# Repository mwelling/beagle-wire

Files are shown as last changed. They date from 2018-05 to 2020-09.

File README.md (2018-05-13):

# beagle-wire

This repository contains the hardware design files for the BeagleWire.

The BeagleWire is an FPGA development platform that has been designed for use with BeagleBone boards.
BeagleWire is a cape on which there is FPGA device - Lattice iCE40HX. The Lattice iCE40 is a family of
FPGAs with a minimalistic architecture and very regular structure, designed for low-cost, high-volume
consumer and system applications. The significance of FPGAs is continuously increasing, as they are more
and more often used for supporting work of ARM processors. BeagleWire does not require external tools
(JTAG) and the whole software stack is Open Source. iCE40 is an energy saving device, allowing to work
with  small batteries. FPGA cape allows easy and low cost start for beginners who would like to take their
first steps in working with FPGAs. The BeagleWire creates a powerful and versatile digital cape for
users to create their imaginative digital designs.

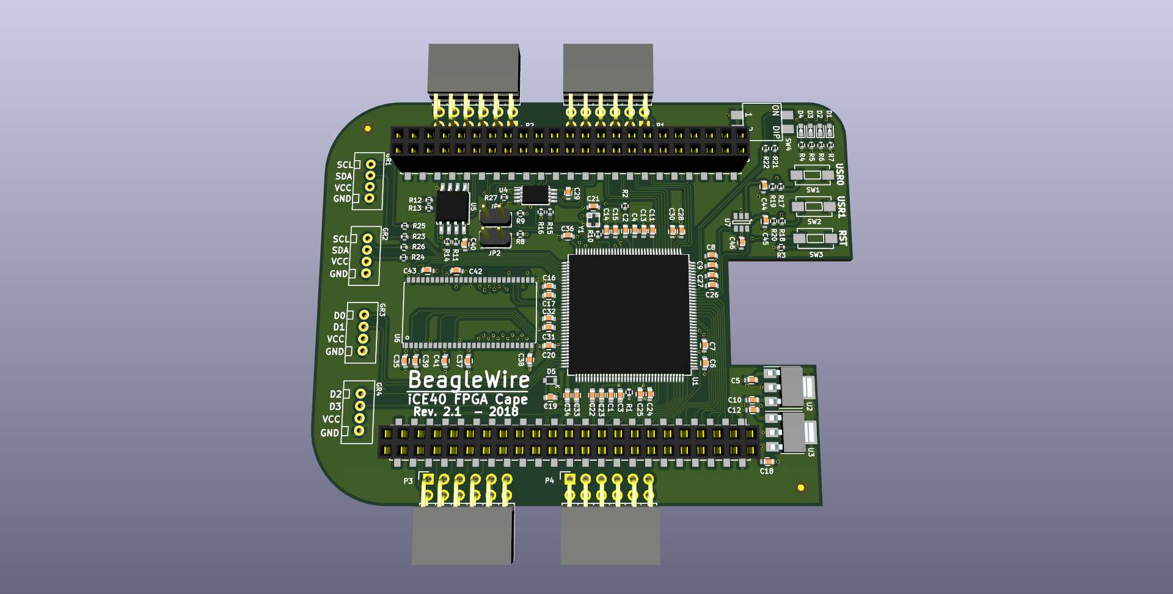
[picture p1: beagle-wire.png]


## Hardware Specification
- FPGA: Lattice iCE40HX4K
- 32 MB SDRAM
- GPIO
- 4 LEDs
- 4 PMOD connectors
- 4 Grove connectors
- 2 user push buttons
- 2 input DIP switch
- 100Mhz external clock
- 4 layer PCB optimized design to support maximum performance for high bandwidth applications
- compatible with BeagleBone Black, BeagleBone Black Wireless, SeeedStudio BeagleBone Green, SeeedStudio BeagleBone Green Wireless, SanCloud BeagleBone Enhanced, element14 BeagleBone Black Industrial

Hardware specification is not complete and may be changed.

## License
Copyright 2017-2018 QWERTY Embedded Design, LLC<br>
Michael Welling <mwelling@ieee.org><br>
Patryk Mezydlo <mezydlo.p@gmail.com>

BeagleWire is licensed under CERN Open Hardware Licence v1.2<br>
[License Information](http://ohwr.org/cernohl)

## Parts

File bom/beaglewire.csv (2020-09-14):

Mfr. # | Manufacturer | Customer # | Description | RoHS | Lifecycle | Order Qty. | Ref Des | Notes
SN74LVC2G14DBVR | Texas Instruments |  | Inverters Dual Schmitt-Trigger | RoHS Compliant |  | 1 | U7
iCE40HX4K-TQ144 | Lattice |  | FPGA - Field Programmable Gate Array iCE40HX 3520 LUTs 1.2V Ultra Low-Power | RoHS Compliant |  | 1 | U1
IS42S83200J-7TLI | ISSI |  | DRAM 256M, 3.3V, SDRAM, 32Mx8, 143MHz, 54 pin TSOP II (400 mil) RoHS, IT | RoHS Compliant |  | 1 | U6
ASDMB-100.000MHZ-LY-T | ABRACON |  | Standard Clock Oscillators 100MHz 10ppm -40C +85C | RoHS Compliant |  | 1 | Y1
EVQ-PE105K | Panasonic |  | Tactile Switches 6.0x3.5mm SMD Light Touch Switch | RoHS Compliant |  | 3 | SW1, SW2, SW3
219-2MST | CTS |  | DIP Switches / SIP Switches SPST 2 switch sections | RoHS Compliant |  | 1 | SW4
LB Q39G-L2OO-35-1 | Osram Opto Semiconductor |  | Standard LEDs - SMD Standard LEDs - SMD Blue, 470nm, 5mA | RoHS Compliant |  | 4 | D1, D2, D3, D4
CDBU0520 | Comchip Technology |  | Schottky Diodes & Rectifiers VR=20V, IO=500mA | RoHS Compliant |  | 1 | D5
110990030 | Seeed Studio |  | Seeed Studio Accessories Grove - Universal 4 pin connector (Pack of 10) | RoHS Compliant |  | 4 | GR1, GR2, GR3, GR4
5-146256-1 | TE Connectivity |  | Headers & Wire Housings 02P HDR DRST B/A 15AU | RoHS Compliant |  | 2 | JP1, JP2
C0603C104M4RAC7411 | Kemet |  | Multilayer Ceramic Capacitors MLCC - SMD/SMT 16V 0.1uF 0603 X7R 20% | RoHS Compliant |  | 23 | C40, C36, C21, C3, C4, C7, C9, C13, C15, C17, C20, C23, C25, C27, C30, C32, C34, C29, C39, C41, C42, C43, C46
LMK107B7105KAHT | Taiyo Yuden |  | Multilayer Ceramic Capacitors MLCC - SMD/SMT 0603 10VDC 1uF 10% X7R AEC-Q200 | RoHS Compliant |  | 17 | C6, C8, C11, C14, C16, C19, C22, C24, C26, C28, C31, C33, C35, C38, C37, C44, C45
LMK107BJ475KA-T | Taiyo Yuden |  | Multilayer Ceramic Capacitors MLCC - SMD/SMT 4.7uF 10V X5R +/-10% 0603 Gen Purp | RoHS Compliant |  | 4 | C5, C10, C18, C12
CC0603KRX5R6BB106 | Yageo |  | Multilayer Ceramic Capacitors MLCC - SMD/SMT 10uF 10% 10V | RoHS Compliant |  | 2 | C1, C2
RC0402JR-0710KL | Yageo |  | Thick Film Resistors - SMD 10K OHM 5% | RoHS Compliant By Exemption |  | 8 | R15, R16, R17, R18, R25, R23, R26, R24
RC0402JR-07240RL | Yageo |  | Thick Film Resistors - SMD 240 OHM 5% | RoHS Compliant By Exemption |  | 4 | R4, R5, R6, R7
RC0402JR-074K7L | Yageo |  | Thick Film Resistors - SMD 4.7K OHM 5% | RoHS Compliant By Exemption |  | 9 | R9, R8, R21, R22, R27, R11, R12, R13, R14
RC0402FR-07100RL | Yageo |  | Thick Film Resistors - SMD 100 OHM 1% | RoHS Compliant By Exemption |  | 5 | R2, R1, R19, R20, R3
RC0402JR-07220RL | Yageo |  | Thick Film Resistors - SMD 220 OHM 5% | RoHS Compliant By Exemption |  | 1 | R10
M7767-05 | Harwin |  | Headers & Wire Housings JUMPER SOCKET CLOSED TOP BLACK | RoHS Compliant |  | 2 | On top of JP1 and JP2
MCP1826S-3302E/DB | Microchip |  | LDO Voltage Regulators 1A CMOS LDO Vout 3.3V ETR | RoHS Compliant |  | 1 | U2
MCP1826S-1202E/DB | Microchip |  | LDO Voltage Regulators 1A CMOS LDO Vout 1.2V ETR | RoHS Compliant |  | 1 | U3
218246M141 |  |  | 2.54mm 2x23pin SMT Female header H8.5mm PA6T |  |  | 2 | P8, P9 (top)
313246M141 |  |  | 2.54mm 2x23pin SMT Male header PA6mm W7.6mm PA6T |  |  | 2 | P8, P9 (bottom)
AT24CS32-XHM-B | Microchip |  | EEPROM S/N SEEPROM 32K I2C1MHz 8-TSSOP | RoHS Compliant |  | 1 | U4
MX25L3206EM2I-12G | Macronix |  | FLASH - NOR Memory IC 32Mb (4M x 8) SPI 86MHz 8-SOP | RoHS Compliant |  | 1 | U5
PPPC062LJBN-RC | Sullins Connector Solutions |  | 12 Position Header Connector Through Hole, Right Angle | RoHS Compliant |  | 4 | P1, P2, P3, P4

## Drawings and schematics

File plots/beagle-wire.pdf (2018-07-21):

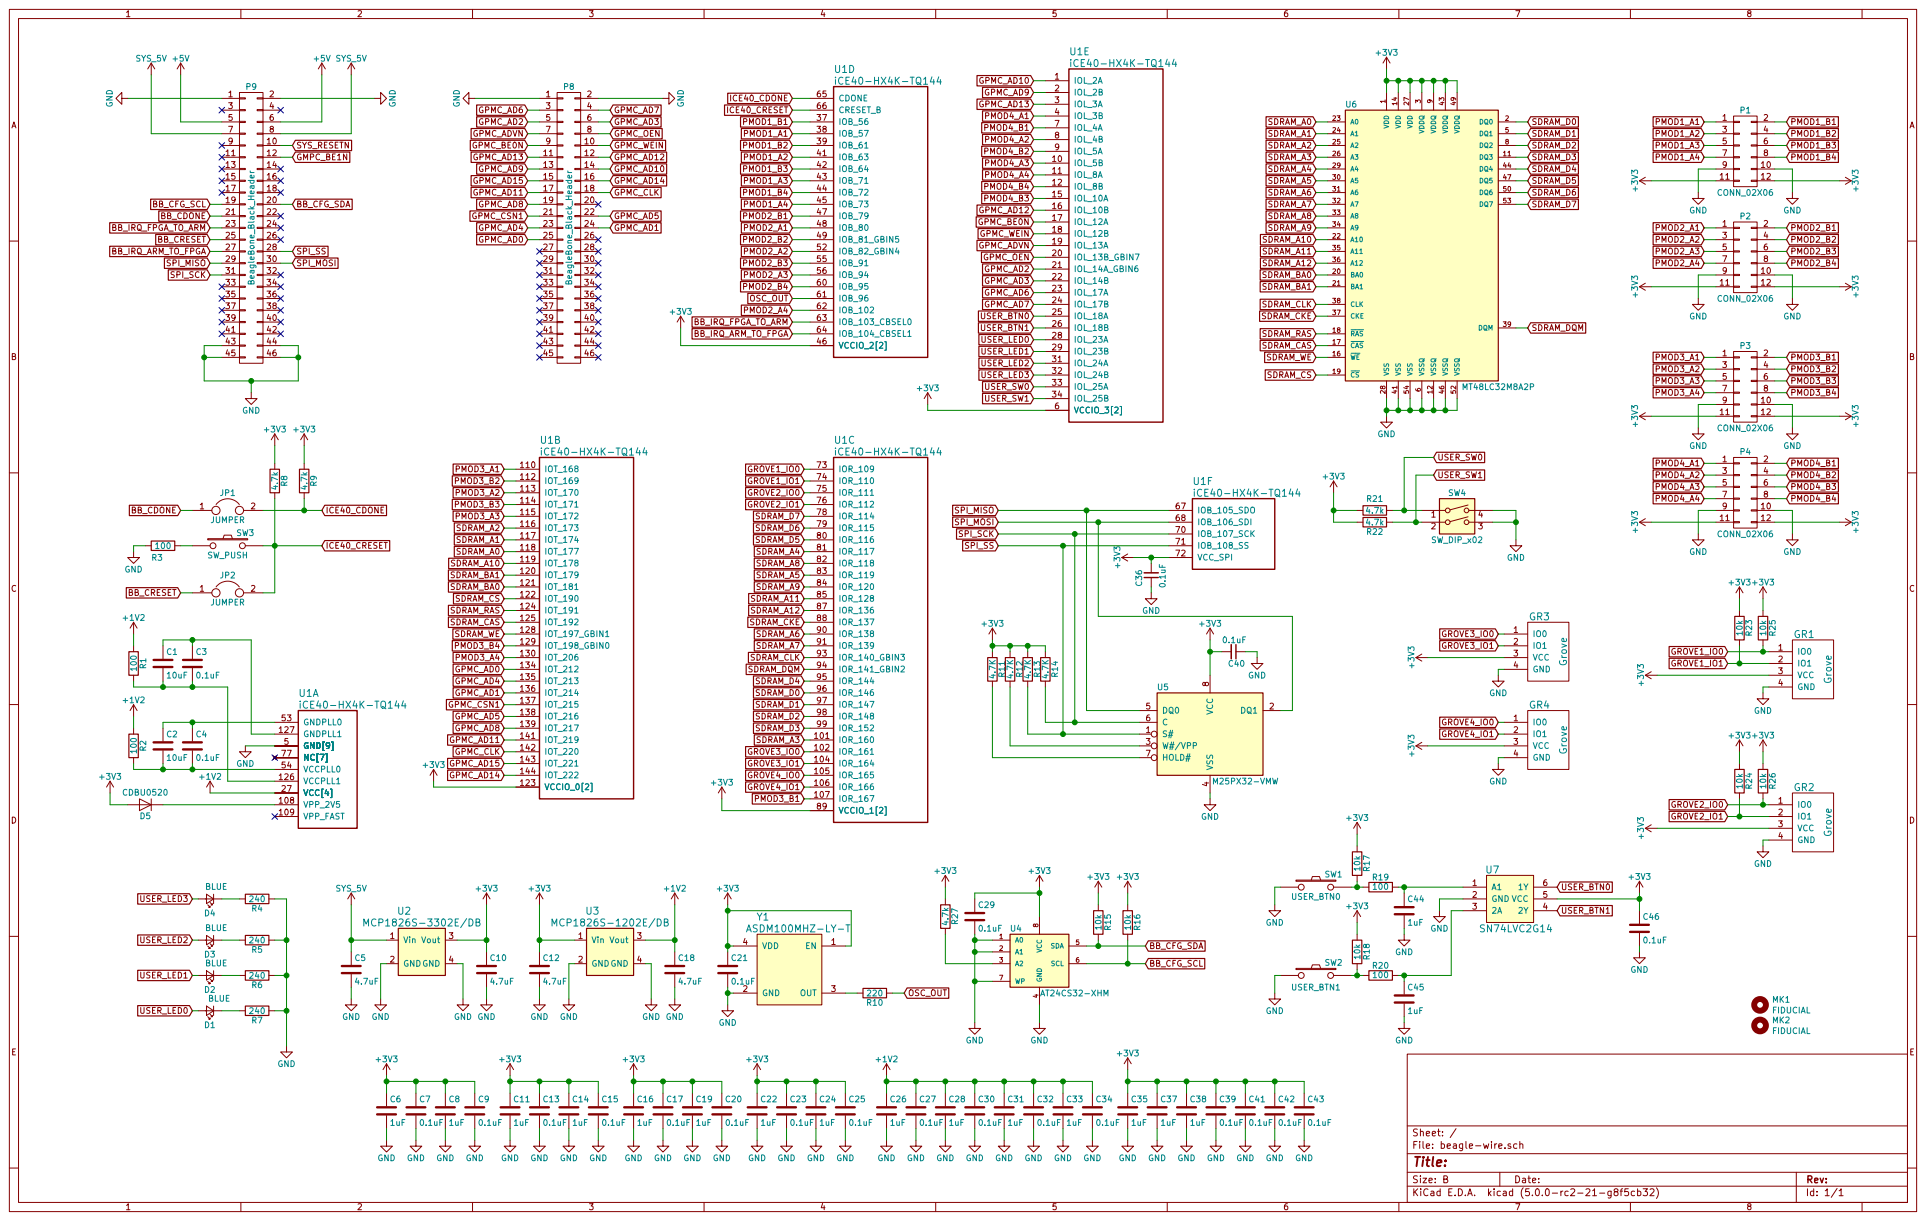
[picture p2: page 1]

1 DQ3 11 VSSQ 12 VDD 14 WE 16 CAS 17 RAS 18 CS 19 DQ0 2 BA0 20 BA1 21 A10 22 A0 23 A1 24 A2 25 A3 26 VDD 27 VSS 28 A4 29 VDDQ

3 A5 30 A6 31 A7 32 A8 33 A9 34 A11 35 A12 36 CKE 37 CLK 38 DQM 39 VSS 41 VDDQ 43 DQ4 44 VSSQ 46 DQ5 47 VDDQ 49 DQ1 5 DQ6 50 VSSQ 52 DQ7 53 VSS 54 VSSQ

0.1uF GND GND GND GND 4.7K R13 4.7K R14

4 SDA 5 SCL 6 WP 7 VCC

0.1uF GND GND GND GND

File: beagle-wire.sch Sheet: /

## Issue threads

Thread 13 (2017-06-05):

8k version

mattvenn, 2017-06-05:
Great project - I'm interested if you ever make a run of boards... but I would prefer an 8k version!

stefanct, 2017-10-19:
i am not associated with the project... but one problem with the 8k is that its available in BGA packages only...

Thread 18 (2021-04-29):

Schematics issue

sbenyamin, 2021-04-29:
Thank you for this board, it is awesome for development.

Two items on the schematics
1.	GPMC_BE1N is misspelled on the schematics as GMPC_BE1N
2.	While GPMC_BE0N is connected to the lattice, GPMC_BE1N is not

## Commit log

2017-03-29 Initial commit
    Some schematic work done based on preliminary spec.
    [beagle-wire.kicad_pcb, beagle-wire.sch]
2017-03-31 Remove local library FPGA
    The symbol is in the cache.
    [beagle-wire.sch]
2017-04-01 add new component to library: - 1V2 power supply flag, - LDO REGULATOR MCP1826S add 3.3v and 1.2v regulators on schematic
    [beagle-wire.sch]
2017-04-01 add 8 user leds
    [beagle-wire.sch]
2017-04-01 add bypass capacitor add 100Mhz oscillator
    [beagle-wire.sch]
2017-04-01 Update schematic look and feel
    Moves the schematic around so that it looks nicer.
    Updates the net labels to be the same smaller size.
    Adds a few resistors to the SPI interface.
    Removes the 3.3V from BB to avoid contention.
    Updates the documentation to indicate 100Mhz oscillator.
    [beagle-wire.sch]
2017-04-01 Add 2 PMOD headers
    No FPGA board is complete without PMOD headers. :)
    [beagle-wire.sch]
2017-04-01 Add SDRAM component
    TODO: Make the SDRAM bigger see notes on schematic.
    [beagle-wire.sch]
2017-04-01 add 4 grove connectors add 2 user buttons add sdram bypass capacitors add EEPROM memory change sdram memory
    [beagle-wire.sch]
2017-04-05 Initial placement / real estate check
    The parts fit but we need to shuffle them around for optimal routing.
    Need footprints for a few components still.
    [beagle-wire.kicad_pcb, beagle-wire.sch]
2017-04-05 add package for dip switch add package for oscillator add dip switch to schematic add 2 pmod connectors relocated elements
    [beagle-wire.kicad_pcb, beagle-wire.sch]
2017-04-05 Fixes board outline
    The endpoints were not connecting quite right.
    [beagle-wire.kicad_pcb]
2017-04-06 Update placement and add 3D print to README
    TODO:
    - Consider adding mounting holes.
    - Reorder nets on FPGA to untangle rats nest.
    [beagle-wire.kicad_pcb, beagle-wire.sch]
2017-04-07 preliminary reord nets on FPGA to untangle rats nest
    [beagle-wire.kicad_pcb, beagle-wire.sch]
2017-04-11 a few improvements of signals placement
    [beagle-wire.kicad_pcb, beagle-wire.sch]
2017-04-13 add 2 layer for power traces add design rules 6mil for signals, 10mil for power line make a few traces for diodes, gpmc, buttons, switches,
    [beagle-wire.kicad_pcb, beagle-wire.sch]
2017-04-14 almost all signals are connected a few amends elements placement
    [beagle-wire.kicad_pcb, beagle-wire.sch]
2017-04-14 Routing complete
    Clean up a bit.
    Might have to remove Beagleboard.org from silkscreen.
    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
    [beagle-wire.kicad_pcb, beagle-wire.sch]
2017-04-14 Tweak routing and remove Beagleboard.org from silk
    [beagle-wire.kicad_pcb]
2017-04-16 new trace for 1v2 new shorter trace for external oscillator
    [beagle-wire.kicad_pcb, beagle-wire.sch]
2017-04-17 Finishing touches
    Ready for design review,
    [beagle-wire.kicad_pcb]
2017-04-17 Make PCB plots go to the plots directory
    To keep the root directory clean.
    [beagle-wire.kicad_pcb]
2017-04-18 connect LDO tab to GND
    [beagle-wire.kicad_pcb, beagle-wire.sch]
2017-05-20 new footprint for DIP Switch and external oscillator add cathode mark on D5 new plots
    [beagle-wire.kicad_pcb, beagle-wire.sch]
2017-05-23 fixed dip switch footprint fixed spi bus issues
    [beagle-wire.kicad_pcb, beagle-wire.sch]
2017-06-08 fixed eeprom address, fixed dip switch,
    [beagle-wire.kicad_pcb, beagle-wire.sch]
2017-08-17 change grove connectors to tht version
    [beagle-wire.kicad_pcb, beagle-wire.sch]
2018-03-22 Update silkscreen for R1
    [beagle-wire.kicad_pcb]
2018-04-02 Add R1 gerbers for reference
    [beagle-wire-B.Cu.gbr, beagle-wire-B.Mask.gbr, beagle-wire-B.Paste.gbr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]
2018-04-16 Add drill files
    [beagle-wire-NPTH.drl, beagle-wire-PTH.drl]
2018-04-16 Add zip file of Gerbers for ease of download
2018-05-13 Switch to SMT headers for manufacturing
    The through-hole headers are not conducive to automation.
    [beagle-wire-B.Cu.gbr, beagle-wire-B.Mask.gbr, beagle-wire-B.Paste.gbr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]
2018-05-16 Add fiducials for manufacturing
    [beagle-wire.kicad_pcb, beagle-wire.sch]
2018-05-16 Update gerbers with added fidos
    [beagle-wire-B.Cu.gbr, beagle-wire-B.Mask.gbr, beagle-wire-B.Paste.gbr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]
2018-05-31 Update for KiCAD 5
    [beagle-wire.sch]
2018-05-31 Manufacturing updates
    Fixed fiducials such that the text is hidden and they appear on both side of the board.
    Plus some little library tweaks.
    [beagle-wire-B.Cu.gbr, beagle-wire-B.Mask.gbr, beagle-wire-B.Paste.gbr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]
2018-05-31 Repackage gerbers
2018-05-31 Add position files for PNP
    [beagle-wire.kicad_pcb]
2018-06-09 Update LED pattern to avoid confusion at fab
    The LEDs polarity marking was not clearly shown after populating the part.
    [beagle-wire.kicad_pcb, beagle-wire.sch]
2018-06-09 Update fabrication files
    [beagle-wire-B.Cu.gbr, beagle-wire-B.Mask.gbr, beagle-wire-B.Paste.gbr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]
2018-07-21 Fix PMOD labelling issue due to mirrored symbol
    The connector was mirrored on the y-axis swapping the A and B side.
    Fixes the schematic as to not confuse people.
    Netlist shuffling only no electrical change.
    [beagle-wire.kicad_pcb, beagle-wire.sch]
2020-04-05 Regenerate plots for new fab
    [beagle-wire-B.Cu.gbr, beagle-wire-B.Mask.gbr, beagle-wire-B.Paste.gbr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]
2020-09-14 Add BOM to repo
    [beaglewire.csv]
